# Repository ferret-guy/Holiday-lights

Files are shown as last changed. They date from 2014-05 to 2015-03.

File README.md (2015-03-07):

Holiday-Magic-Lights code

All recent developments are in ./HolidayLights/led_ir

Developed on Aquino IDE 1.05 and Arduino IDE 1.5.6r2

Todo:
    Add Basic Animations
        Scrolling
        Twinkling
        Rainbow
    Add more colors
	Add IR capability
	Fix even-number separation modes

NOTES:
Writing to strip of 144 length is 1.25ms
Writing to strip of 045 length is 1.35ms (what?)
Writing to strip of 189 length is 1.58ms
Writing to strip of 300 length is 1.85ms (specified maximum)

MODES:
0 - Off
1 - Separation Mode (Including Chaser Mode)
2 - Solid Mode
3 - Rainbow Mode
4 - Blink Mode
5 - Twinkle Mode

SPECIAL CONTROLS:
Special features activated through mode button (5th row, 2nd column):

1.
In Separation Mode, Switches through seperation modes (Starts at 1, goes to 2, then 3, then 0, then 1 again)
Mode number is now many times each color occurs.
!! Separation mode 0 is chaser mode. !!

2.
In Solid Mode, cycles through preset strip lengths. IN DEVELOPMENT FIRMWARE, THIS IS:
	45 long, 144 long, 189 long, then 45 long again.
THIS WILL BE CHANGED TO INTERVALS OF 60 FOR PRODUCTION?

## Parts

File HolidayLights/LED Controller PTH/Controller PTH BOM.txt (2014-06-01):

   ╔═════════════════════════════════════════════════╗
   ║LED Controller PTH Prototype -- Bill of Materials║
╔══╩════════════╦═══════╦═══════════════════╦════════╩══╗
║ Component     ║ Name  ║ Digikey P/N       ║ Price     ║
╠═══════════════╬═══════╬═══════════════════╬═══════════╣
║ 0.1uF         ║ C1    ║ 399-9845-ND       ║ $0.45     ║
║ 0.1uF         ║ C2    ║ 399-9845-ND       ║ $0.45     ║
║ 0.1uF         ║ C5    ║ 399-9845-ND       ║ $0.45     ║
║ 0.1uF         ║ C6    ║ 399-9845-ND       ║ $0.45     ║
║ 0.33uF        ║ C3    ║ 493-12794-1-ND    ║ $0.17     ║
║ 1uF           ║ C4    ║ UKL1H010KDDANA-ND ║ $0.42     ║
║ ATMEGA328-P   ║ IC1   ║ ATMEGA328-PU-ND   ║ $3.41     ║
║ CONN_3        ║ K1    ║ 5-826951-0-ND     ║ $0.20*    ║
║ CONN_6        ║ P1    ║ 5-826951-0-ND     ║ $0.40*    ║
║ TSOP38238     ║ Q1    ║ 751-1227-ND       ║ $1.12     ║
║ ZTT-16.00MX   ║ Q2    ║ X908-ND           ║ $0.70     ║
║ 300           ║ R2    ║ CF14JT300RCT-ND   ║ $0.08     ║
║ 10K           ║ R1    ║ CF14JT10K0CT-ND   ║ $0.08     ║
║ LM7905CT      ║ U1    ║ NCP7805TGOS-ND    ║ $0.46     ║
╠═══════════════╬═══════╬═══════════════════╬═══════════╣
║ TOTAL COST    ║░░░░░░░║░░░░░░░░░░░░░░░░░░░║ $11.54    ║
╠═══════════════╩═══════╩═══════════════════╩═══════════╣
║*Calculated from total cost of 50-position breakaway.  ║
║ Total cost is increased due to this.                  ║
╚═══════════════════════════════════════════════════════╝

201 205 203 205 187 ╔═╦═╗
186 176 186 177 186 ║░║▒║
204 205 206 205 185 ╠═╬═╣
186 178 186 219 186 ║▓║█║
200 205 202 205 188 ╚═╩═╝

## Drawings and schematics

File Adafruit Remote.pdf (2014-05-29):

# Adafruit IR Codes

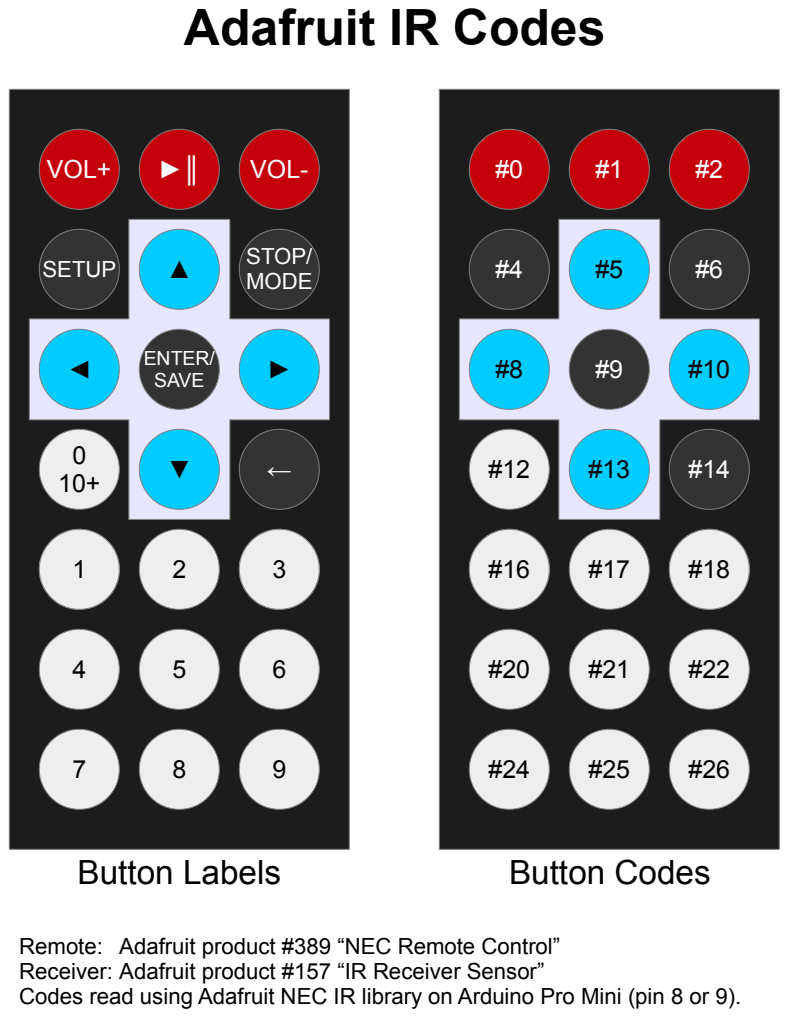
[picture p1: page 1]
VOL+; VOL-; SETUP; STOP/; MODE; ENTER/ SAVE; Button Labels; Button Codes

Remote: Adafruit product #389 “NEC Remote Control”
Receiver: Adafruit product #157 “IR Receiver Sensor”
Codes read using Adafruit NEC IR library on Arduino Pro Mini (pin 8 or 9).

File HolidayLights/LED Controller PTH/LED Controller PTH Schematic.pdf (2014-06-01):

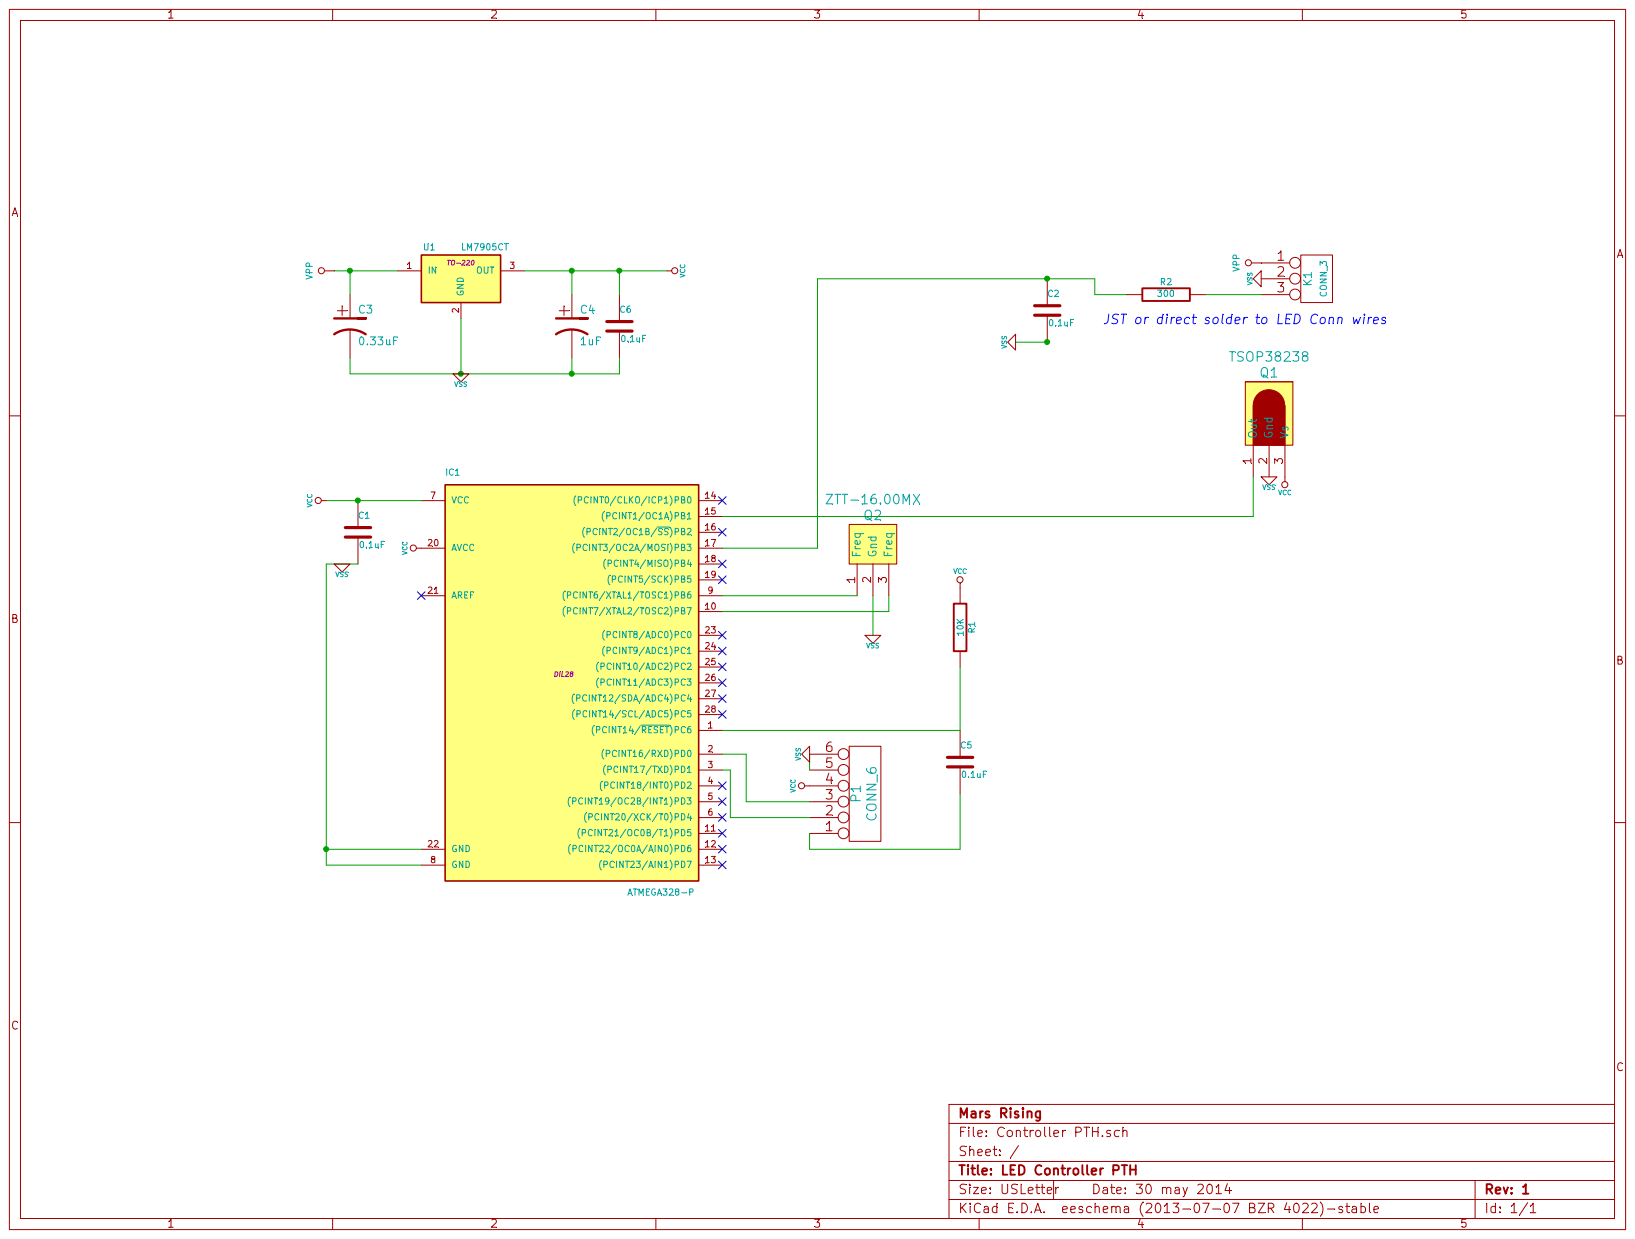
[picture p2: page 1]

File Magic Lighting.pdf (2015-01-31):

# “Magic Lighting” Remote IR Codes

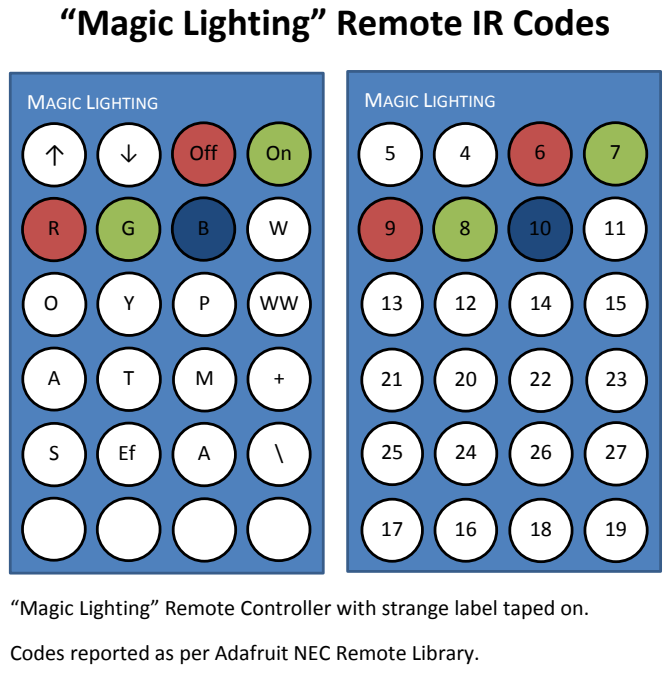
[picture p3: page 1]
MAGIC LIGHTING; Off

“Magic Lighting” Remote Controller with strange label taped on.

Codes reported as per Adafruit NEC Remote Library.

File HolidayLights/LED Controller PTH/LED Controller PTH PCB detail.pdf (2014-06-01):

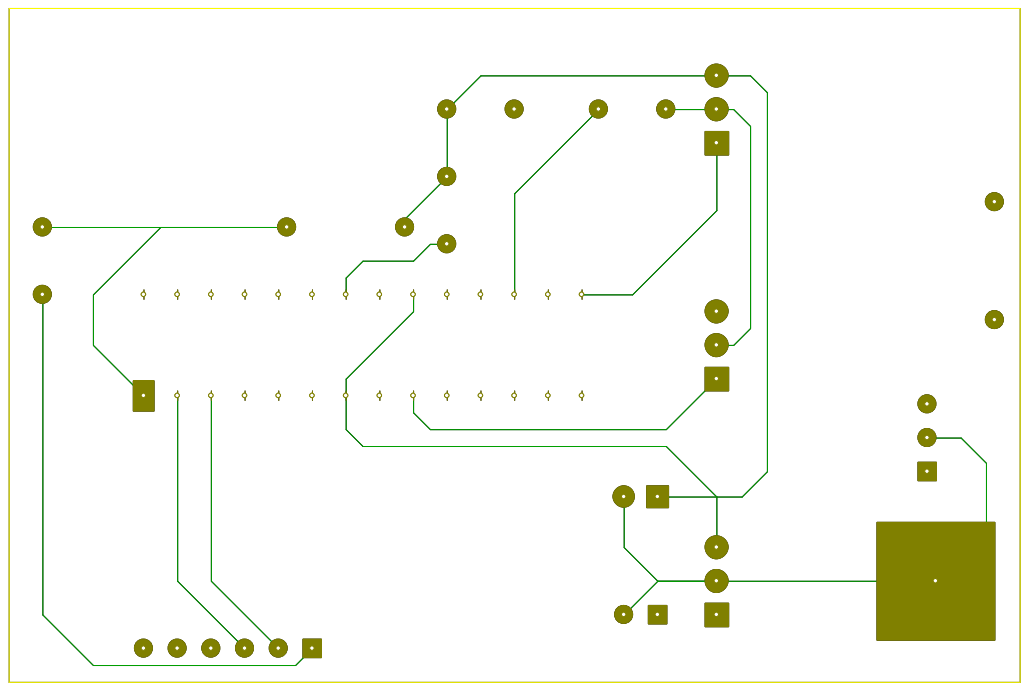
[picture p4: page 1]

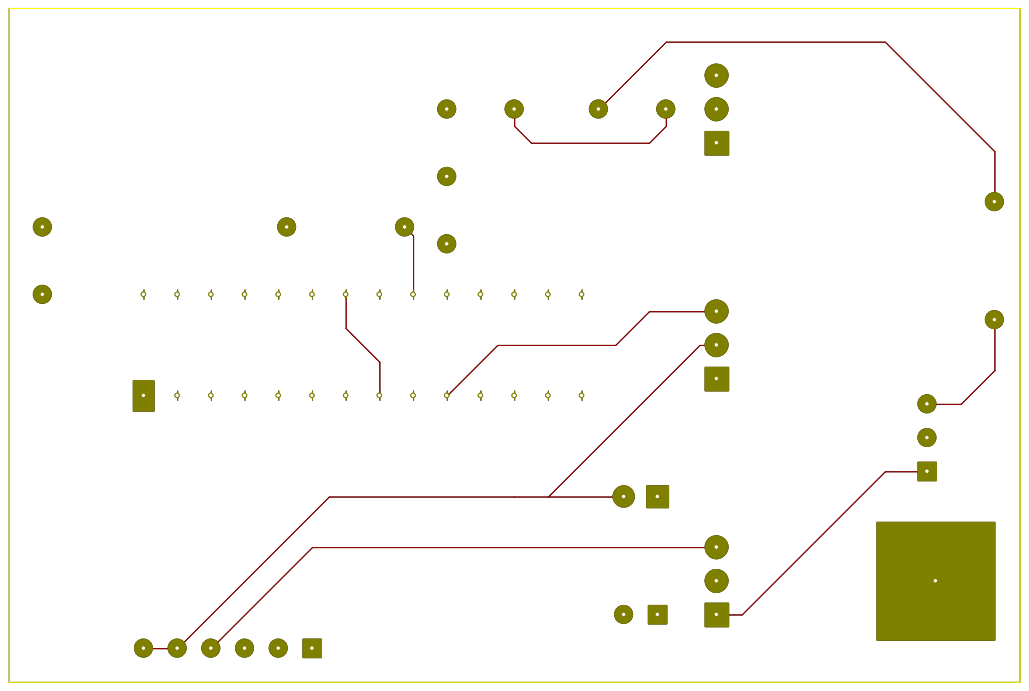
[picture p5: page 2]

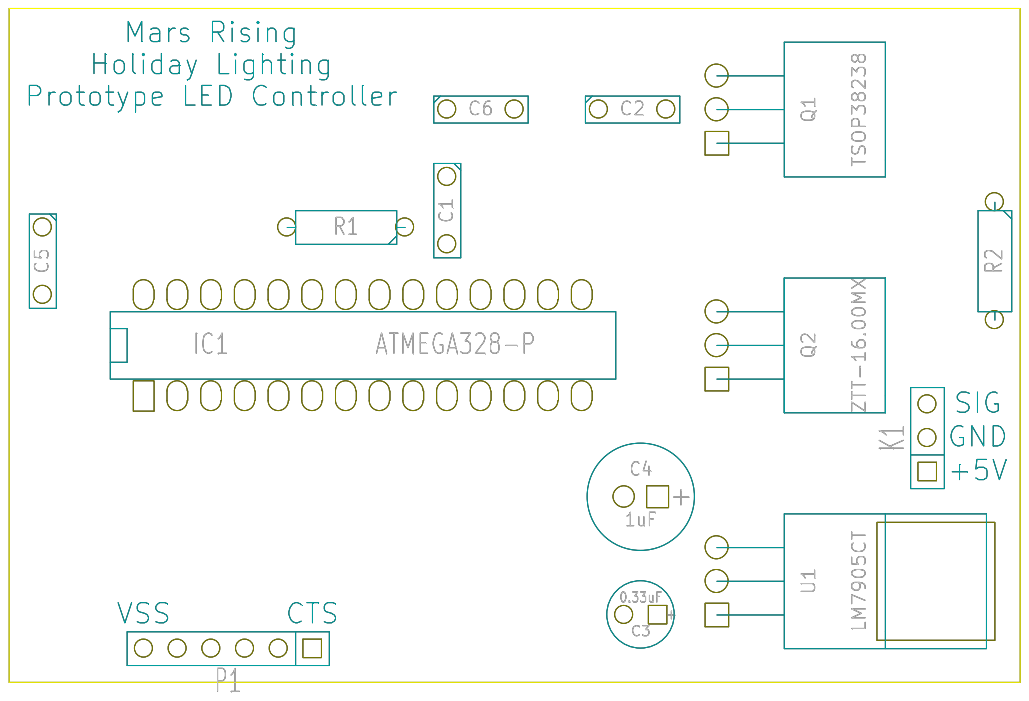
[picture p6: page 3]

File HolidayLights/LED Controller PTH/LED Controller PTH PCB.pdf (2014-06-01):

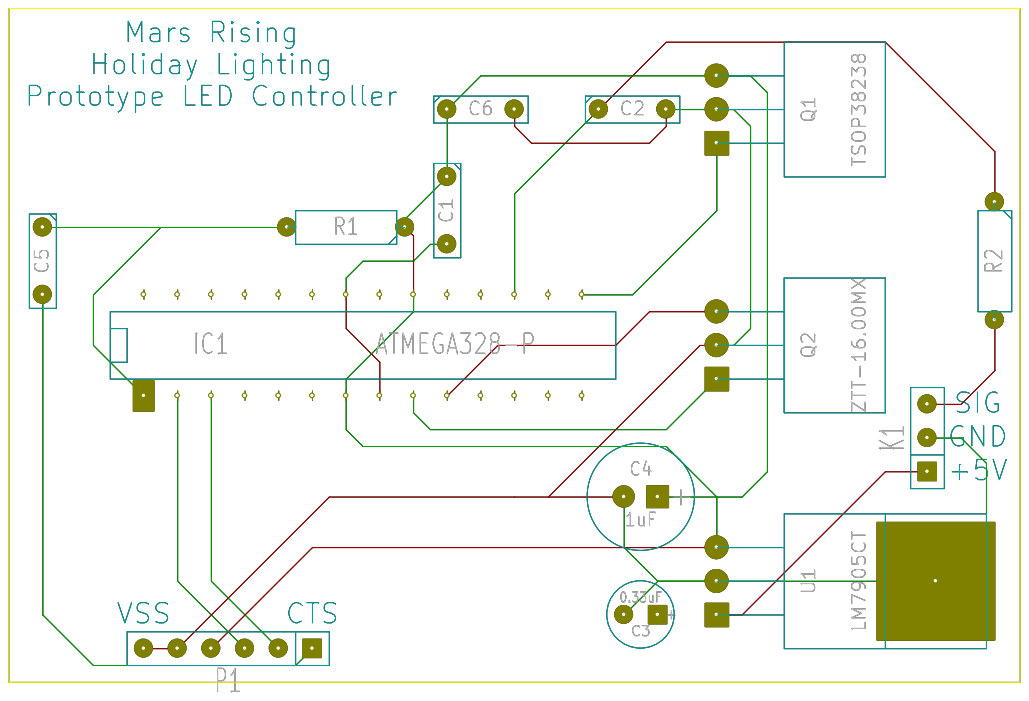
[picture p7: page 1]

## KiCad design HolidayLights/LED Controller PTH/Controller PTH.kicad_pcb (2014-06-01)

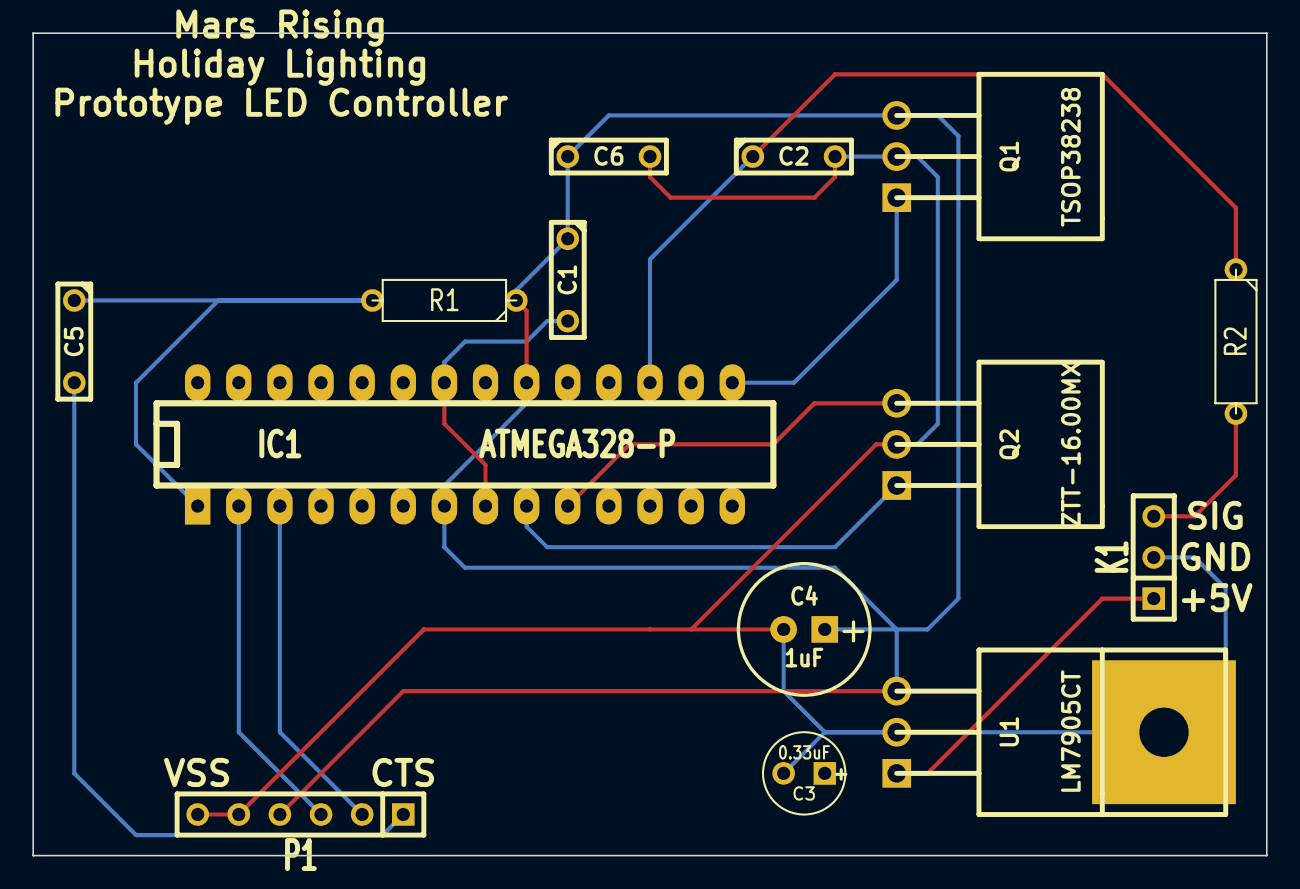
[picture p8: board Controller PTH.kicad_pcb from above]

Board: 2 copper layers, 76.2 x 50.8 mm, 14 parts (0 on the bottom side), 13 nets.

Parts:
C1, C2, C5, C6: 0.1uF; C2
C3: 0.33uF; C1V5
C4: 1uF; C1V8
IC1: ATMEGA328-P; DIP-28__300_ELL
K1: CONN_3; SIL-3
P1: CONN_6; SIL-6
Q1: TSOP38238; TO220
Q2: ZTT-16.00MX; TO220
R1: 10K; R3-5
R2: 300; R3-5
U1: LM7905CT; TO220

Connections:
unnamed: C5.1, IC1.1, R1.2
unnamed: IC1.3, P1.2
unnamed: C5.2, P1.1
unnamed: K1.3, R2.2
unnamed: IC1.15, Q1.1
unnamed: C2.1, IC1.17, R2.1
unnamed: C1.2, IC1.8, IC1.22
unnamed: IC1.9, Q2.1
unnamed: IC1.10, Q2.3
unnamed: IC1.2, P1.3
VCC: C1.1, C4.1, C6.1, IC1.7, IC1.20, P1.4, Q1.3, R1.1, U1.3
VPP: C3.1, K1.1, U1.1
VSS: C2.2, C3.2, C4.2, C6.2, K1.2, P1.5, P1.6, Q1.2, Q2.2, U1.2

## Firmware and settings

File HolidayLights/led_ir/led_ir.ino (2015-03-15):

#include "AdafruitNECIR.h"
#include <Adafruit_NeoPixel.h>



// ****************************************** Defines and Globals Go Here

//Pin the strip is on.
#define PIN 7
//Pin the IR Sensor is on.
#define IRpin 3

//Serial Definitions
#define STARTBIT          253
#define STOPBIT           254
#define FILLSTRIPSIG      44
#define UPDATECOLORSIG    50
#define PREVIEWPIXELSIG   60
#define SETPIXELSIG       61
#define CLEARPIXELSIG     62
#define CHANGECOLSIG      30
#define SEPMODESIG        40
#define KILLSEPBIT        31

#define NUMMODES          6        //Number of modes, including off.
#define NUMLENGTHS        3        //Number of preset lengths.
#define MAXLEDS           300      //Specified maximum number of LEDS.

#define MINCOLORS         1        //The minimum number of colors allowed in separation mode. i.e. the user can turn off colors until they have this many.
#define MAXSPEED          20       //Maximum animation speed in milliseconds.
#define MINSPEED          250      //Minimum animation speed in milliseconds. Below this speed stops moving.
#define SPEEDSTEP         15       //The time by which speed in adjusted in milliseconds.

//Define our globals.
int       led_num         = 144;    //Total number of LEDs, zero-ordinated.
int       cur_len         = 1;     //The current length preset.
int       col_tot         = 11;    //Total colors defined. This will almost certainly be 11, but there's nothing wrong with a little open-endedness.
int       col_len         = 0;     //The length of each color segment. This is calculated later.
float     col_fln         = 0;     //The floating-point color length.
int       col_seg         = 0;     //The length of each separation mode segment.
int       col_num         = 0;     //The number of active/enabled colors. This is calculated later.
int       col_rep         = 0;     //The number of times to draw the colors in color separation mode 2+.
int       ren_stp         = 0;     //The number of iterations the rendering loop goes through before resetting. This is calculated later.
int       ren_stp_b       = 256;   //Rainbow steps.
int       ren_glx         = 0;     //Useful for resuming color separation mode as opposed to restarting the animation.
int       ren_glx_b       = 0;     //Useful for rainbows.
int       ren_bri         = 255;   //Global brightness multiplier. 255 is fullbright, 0 is blackout.
int       sep_mod         = 1;     //The current separation mode.
int       sep_prv         = 1;     //The previous separation mode.
int       sep_dly         = 265;   //The current animation frame delay.
int       absolute_offset = 0;     //The number of pixels to skip when drawing. Artifact from an old devkit.
int       cmd_last        = 0;     //The last IR code recieved.
int       cmd_prev        = 0;     //The one before that.
int       mode_state      = 0;     //The current mode.
int       mode_last       = 1;     //The mode before we turned off. Also lets us turn on to solid mode, apparently.
int       ani_dir         = 0;     //Direction of animation progression, 0 is forward, 1 is reverse.
int       ani_go          = 0;     //Should the animation be going?
int       efc_col         = 3;     //Current color for Twinkle and Blink

//Initialize our strip. There needs to be a way to clear this out, because when additional physical LED strips are added, the length can only be changed by redefining the strip.
Adafruit_NeoPixel strip = Adafruit_NeoPixel(MAXLEDS+absolute_offset+1, PIN, NEO_GRB + NEO_KHZ800);
//Initialize our IR sensor.
Adafruit_NECremote remote(IRpin);

//Colors:
//0.  Red
//1.  Green
//2.  Blue
//3.  White
//4.  Orange
//5.  Yellow
//6.  Purple
//7.  Warm White
//8.  Turquoise
//9.  Magenta
//10. Amber

//Mask of enabled colors.
boolean color_enable[] = {0,0,0,1,0,0,0,0,0,0,0};
//The color definitions themselves.
uint32_t colors[] = {
  strip.Color(255,0,0),      //Red
  strip.Color(0,255,0),      //Green
  strip.Color(0,0,255),      //Blue
  strip.Color(255,255,255),  //White
  strip.Color(255,100,0),    //Orange
  strip.Color(255,255,0),    //Yellow
  strip.Color(128,0,128),    //Purple
  strip.Color(255,178,48),   //Warm White
  strip.Color(175,238,238),  //Turquoise
  strip.Color(255,0,128),    //Magenta
  strip.Color(255,200,25)    //Amber
};

//Alternatively, for twinkle...
int colorparts[11][3] = {
  {255,0,0},
  {0,255,0},
  {0,0,255},
  {255,255,255},
  {255,100,0},
  {255,255,0},
  {128,0,128},
  {255,178,48},
  {175,238,238},
  {255,0,128},
  {255,200,25}
};

//Predefined, switchable strip lengths.
int lengths[] = {
  45,
  144,
  189
};

//MODE TABLE - Important stuff.
void (*modes[])() = {
  *ModeOffHndlr,
  *ModeSepModHndlr,
  *ModeSolidHndlr,
  *ModeRainbowHndlr,
  *ModeBlinkHndlr,
  *ModeTwinkleHndlr
};
  

// ****************************************** General Purpose Functions Go Here

//Literally Nothing
void dust(){}

//Nothing For Your Something
void dust2(int cs_s){}

//Calculate the length of each color segment based on the length of the strip and the separation mode. (This is col_len.)
int CalcCL(int spm){
  //Preset the color length to one, in case separation mode is zero.
  int ccl = 1;
  //If separation mode is non-zero...
  if(spm>0){
    //The color length is calculated.
    if(col_num>0){
      ccl = ceil(((led_num/spm)/col_num));
      if(ccl<1){ccl=1;}
      //Calculate the floating-point color length.
      col_fln = (led_num/spm)/col_num;
      col_seg = (int) (ccl*col_num);
      col_rep = led_num/col_seg;
    }else{ccl=1;}
  }
  return ccl;
}

//Calculate the number of colors enabled. (This is col_num.)
int CalcCN(boolean cle[]){
  int cur=0;
  //Iterate through the color_enable mask and add one to the proto-col_num everytime we find a high bit.
  for(int cc=0;cc<col_tot;cc++){
    if(cle[cc]){cur++;}
  }
  if(cur==0){cur=1;}
  return cur;
}

//Initialize our strips(s). This is where strip redefinition would need to happen.
void initStrips(boolean cle[],int spm){
  //Update our globals.
  col_num = CalcCN(cle);
  col_len = CalcCL(spm);
  //Set the number of render steps.
  if(spm>0){
    ren_stp = col_seg;
  }else{
    ren_stp = led_num;
  }
  //Initialize our strip.
  strip.begin();
  strip.setBrightness(ren_bri);
  strip.show();
}

//Fill the strip with a color.
void FillStrip(int cr, int cg, int cb){
  //Construct the selected color.
  uint32_t nc=strip.Color(cr,cg,cb);
  //Step through each pixel and set it to the selected color.
    for(int i=0;i<=led_num;i++){
      strip.setPixelColor(i+absolute_offset,nc);
  }
}

//Fill the strip with a predefined color.
void FillStripC(uint32_t nc){
  //Step through each pixel and set it to the selected color.
    for(int i=0;i<=led_num;i++){
      strip.setPixelColor(i+absolute_offset,nc);
  }
}

//Adafruit colorwheel function... no need to reinvent the wheel.
uint32_t Wheel(byte WheelPos) {
  WheelPos = 255 - WheelPos;
  if(WheelPos < 85) {
   return strip.Color(255 - WheelPos * 3, 0, WheelPos * 3);
  } else if(WheelPos < 170) {
    WheelPos -= 85;
   return strip.Color(0, WheelPos * 3, 255 - WheelPos * 3);
  } else {
   WheelPos -= 170;
   return strip.Color(WheelPos * 3, 255 - WheelPos * 3, 0);
  }
}

//Increment or decrement a variable to progress animation.
int progressAnimation(int input){
  int output;
  //Serial.println("got called");
  //Serial.println(input);
  if(ani_go==1){
    if(ani_dir==1){
      //Serial.println("minus minus");
      output = input-1;
    }else{
      //Serial.println("plus plus");
      output = input+1;
    }
  }else{
    output=input;
  }
  //Serial.println(output);
  return output;
}



// ****************************************** Renderers Go Here

//The separation mode renderer!
void RenderSPM(int offset){
  //Initialize the incrementing variables.
  int rend_step = 1; //NOT TO BE CONFUSED WITH ren_stp.
  int col_step = 0;
  int spm_step = -1;
  //Make sure we have a workable number of colors
  if(col_num>1){
    //If separation mode is 1 or higher...
    if(sep_mod>0){
      //This while loop increments spm_step to draw multiple instances of the separation for modes 2 and up.
      while(spm_step<=col_rep){
        col_step=0;
        rend_step=0;
        //This while loop steps through the different colors.
        while(col_step<col_tot){
          //If the color is enabled, render it.
          if(color_enable[col_step]){
            //Calculate what pixel we should be drawing to.                 \/ This is where we move over a lot for separation mode 2+.
            int pixnum=(rend_step*(col_len))+offset+(col_seg*spm_step);
            //Don't draw to pixels lower than the absolute offset.
            if(pixnum<0){
              pixnum=-absolute_offset-1;
            }
            //Draw the pixel in the correct color.
            strip.setPixelColor(pixnum+absolute_offset,colors[col_step]);
            //Go to the next color length.
            rend_step++;
          }
          //Go to the next color.
          col_step++;
        }
        //Draw the next separation instance.
        spm_step++;
      }
    //Draw separation mode 0. We handle this separately as the effect achived is actually the expected result of the separation mode approaching infinity, where as true mode zero would be a single color of infinite length.
    }else{
      //Pretty simple stuff. It won't need changing, ever.
      //Calculate how many times the pattern needs repeating.
      int led_rpt=led_num/col_num;
      //Initialize a thing.
      int pixnum=0;
      int stepnum=0;
      //Step through the colors.
      while(col_step<col_tot){
        //If a color is enabled, draw it.
        if(color_enable[col_step]){
          //Repeat it however many times with the offset increased by the total colors.
          for(int i=0;i<led_num;i+=col_num){
            pixnum = stepnum+i+offset;
            if(pixnum>=led_num){pixnum-=led_num;}
            //Actually draw the pixel.
            strip.setPixelColor(pixnum+absolute_offset,colors[col_step]);
          }
          stepnum++;
        }
        //Go to the next color.
        col_step++;
      }
    }
  //If there is only one color enabled, it is a solid mode.
  }else if(col_num==1){
    //Look until we find the enabled color.
    while(col_step<col_tot){
      if(color_enable[col_step]){
        FillStripC(colors[col_step]);
      }
      //Go to the next color.
      col_step++;
    }
  //If there are no colors enabled, draw black, so as to not break everything.
  }else{
    FillStrip(0,0,0);
  }
  //Actually send all these changes to the strip. We do this SOMEWHERE ELSE for due to major opimization issues, as well as to avoid visually staggered rendering.
  //strip.show();
}

//Predraw all the pixels so separation mode doesn't fill over initial black.
void SPMPreRender(int offs){
  for(int x=offs;x<col_len+offs;x++){
    RenderSPM(x);
  }
  strip.show();
}

//Do a rainbow.
void RenderRainbow(uint16_t j) {
  uint16_t i;
    for(i=0; i<strip.numPixels(); i++) {
      strip.setPixelColor(i, Wheel((i+j) & 255));
    }
    strip.show();
}

//Twinkly.
void RenderTwinkle(int index){
  int n;
  for(n=0;n<(led_num/4);n++){
    float r = (float) colorparts[index][0];
    //float r = 255;
    float g = (float) colorparts[index][1];
    //float g = 0;
    float b = (float) colorparts[index][2];
    //float b = 0;
    float di = (float) random(100);
    float d = (di/125)+0.2;
    r = r*d;
    g = g*d;
    b = b*d;
    int ri = (int) r;
    int gi = (int) g;
    int bi = (int) b;
    uint32_t color = strip.Color(ri,gi,bi);
    strip.setPixelColor(random(led_num),color);
  }
  strip.show();
}
    


// ****************************************** Button Handlers Go Here

//Handle mode button in sepmod
void SepModModeHndlr(){
  if (sep_mod == 3){sep_mod = 0;}
  else {sep_mod++;}
  ren_glx = 0;
}

void colenable(int index){
  if(col_num>MINCOLORS){
    if (color_enable[index]==1){
      color_enable[index]=0;
    }else{
      color_enable[index]=1;
    }
    ren_glx = 0;
  }else{color_enable[index]=1;}
}

void BlinkTwinkleColorHndlr(int index){
  efc_col=index;
}

void SolidColorHndlr(int index){
  FillStripC(colors[index]);
}

void SolidModeHndlr(){
  cur_len++;
  if(cur_len==NUMLENGTHS){cur_len=0;}
  led_num=lengths[cur_len];
  initStrips(color_enable,sep_mod);
}



// ****************************************** Top-Level Handlers Go Here

//Single byte command processor. This is split out so that we can take commands during ANY MODE with ease. Handlers for mode-specific events are passed in.
int SingleByteCommand(int csig, void (*colHndlr)(int), void (*modHndlr)(), bool volatileColors){
  int gret=0;
  
  //colHndlr is called when any color button is pressed, parameter passed is color number as per array up top.
  //modHndlr is called when mode button is pressed, no paramter is passed.
  
  switch(csig){
    //DO COLORS
    //Red
    case 9:
      colHndlr(0);
      if(!volatileColors){gret=1;}
      break;
      
    //Green
    case 8:
      colHndlr(1);
      if(!volatileColors){gret=1;}
      break;
    
    //Blue
    case 10:
      colHndlr(2);
      if(!volatileColors){gret=1;}
      break;
  
    //White
    case 11: 
      colHndlr(3);
      if(!volatileColors){gret=1;}
      break;
    
    //Orange
    case 13:
      colHndlr(4);
      if(!volatileColors){gret=1;}
      break;
    
    //Yellow
    case 12:
      colHndlr(5);
      if(!volatileColors){gret=1;}
      break;
    
    //Purple
    case 14:
      colHndlr(6);
      if(!volatileColors){gret=1;}
      break;
    
    //Warm White
    case 15:
      colHndlr(7);
      if(!volatileColors){gret=1;}
      break;
    
    //Turquoise
    case 20:
      colHndlr(8);
      if(!volatileColors){gret=1;}
      break;
    
    //Magenta
    case 22:
      colHndlr(9);
      if(!volatileColors){gret=1;}
      break;
    
    //Amber
    case 21:
      colHndlr(10);
      if(!volatileColors){gret=1;}
      break;
    
    //DO ADJUSTMENTS
    //Speed Down
    case 27:
      sep_dly+=SPEEDSTEP;
      if(sep_dly>MINSPEED){
        sep_dly=MINSPEED+SPEEDSTEP;
      }
      if(sep_dly>MINSPEED){ani_go=0;}
      gret=1;
      break;
    
    //Speed Up
    case 23:
      sep_dly-=SPEEDSTEP;
      if(sep_dly<MAXSPEED){
        sep_dly=MAXSPEED;
      }
      if(sep_dly<=MINSPEED){ani_go=1;}
      gret=1;
      break;
    
    //Brightness Down
    case 4:
      ren_bri-=15;
      if(ren_bri<15){
        ren_bri=15;
      }
      gret=1;
      strip.setBrightness(ren_bri);
      break;
    
    //Brightness Up
    case 5:
      ren_bri+=15;
      if(ren_bri>255){
        ren_bri=255;
      }
      gret=1;
      strip.setBrightness(ren_bri);
      break;
    
    //DO THESE MISCELLANEOUS STUFF
    //Mode Button Handler
    case 24:
      modHndlr();
      break;
    
    //Someone held down the button, and we haven't implemented that yet.
    case -3:
      gret=1;
      break;
    
    //Reverse the animation progression.
    case 19:
      if(ani_dir==1){
        ani_dir=0; //forward
      }else{
        ani_dir=1; //reverse
      }
      gret=1;
      break;
    
    //DO MODES
    //Turn On
    case 7:
      if(mode_state!=0){gret=1;}
      if(mode_last==0){mode_last=1;}
      mode_state=mode_last;
      break;
    
    //Off Mode
    case 6:
      if(mode_state!=0){
        mode_last=mode_state;
      }
      mode_state=0;
      break;
    
    //Separation Mode
    case 26:
      mode_state=1;
      break;
    
    //Solid Mode
    case 25:
      mode_state=2;
      break;
    
    //Rainbow Mode
    case 17:
      mode_state=3;
      break;
    
    //Blink Mode
    case 16:
      mode_state=4;
      break;
    
    //Twinkle Mode
    case 18:
      mode_state=5;
      break;
      
    default:
      gret=1;
      break;
    
  }  
  return gret;
}

//Accept commands and be blank.
void ModeOffHndlr(){
  FillStrip(0,0,0);
  strip.show();
  while(1==1){
    cmd_last=remote.listen(250);
    int cret=SingleByteCommand(cmd_last,*dust2,*dust,false);
    if(cret==0){break;}
  }
}

//Run separation mode.
void ModeSepModHndlr(){
  //Re-intialize the strip with the selected parameters.
  initStrips(color_enable,sep_mod);
  //Initialize our breaking var.
  int i=1;
  //If we're not resuming separation mode, predraw the colors so we don't have empty pixels visible.
  if(ren_glx==0){
    //Render a single color-length.
    SPMPreRender(0);
    //Update our resume variable for when we actually start rendering.
    ren_glx=col_len;
  }else{
    SPMPreRender(ren_glx-col_len);
  }
  //Keep going until told to stop.
  while(i==1){
    //Run through the calculated number of rendering steps. Start where we stopped.
    //for(int x=ren_glx;x<ren_stp;progressAnimation(x)){
      //Serial.println("start");
      //Serial.println(ren_glx);
      int x = ren_glx;
      //Render it!
      RenderSPM(x);
      strip.show();
      x = progressAnimation(x);
      
      //Keep track of where we are so that we can pause and resume.
      ren_glx=x;
      //Delay the animation by the selected amount, and get an IR command. Two stones with one bird.
      cmd_last = remote.listen(sep_dly);
      //Serial.println("progresses");
      //Serial.println(ren_glx);
      int cret = 1;
      if(cmd_last>0){cret=SingleByteCommand(cmd_last,*colenable,*SepModModeHndlr,true);}//Run the IR command.
      //Serial.println(cret);
      //if(cmd_last==6||cmd_last==25){i=0;FillStrip(0,0,0);strip.show();break;}//If the command is right, break from the sepmod loop.
      if(cret==0){initStrips(color_enable,sep_mod);ren_glx=col_len;SPMPreRender(0);break;}//Reset and restart sepmod for necessary changes
      cmd_last = 0;//Make sure we don't re-run commands.
    //}
    //If we've made a full render, go back to rendering step zero.
    if(ani_dir==1){
      if(ren_glx==0){
        ren_glx=(ren_stp);
      }
    }else{
      if(ren_glx==(ren_stp)){
        ren_glx=0;
      }
    }
  }
}

//Does solid colors.
void ModeSolidHndlr(){
  initStrips(color_enable,sep_mod);
  int i=1;
  FillStrip(255,255,255);
  while(i==1){
    cmd_last=remote.listen(250);
    int cret = SingleByteCommand(cmd_last,*SolidColorHndlr,*SolidModeHndlr,false);
    strip.show();
    if(cret==0){i=0;break;}
    cmd_prev=cmd_last;
  }
  //FillStrip(0,0,0);
  //strip.show();
}

//Make it rainbow.
void ModeRainbowHndlr(){
  //Re-intialize the strip with the selected parameters.
  initStrips(color_enable,sep_mod);
  //Initialize our breaking var.
  int i=1;

  //Keep going until told to stop.
  while(i==1){
      int x = ren_glx_b;
      //Render it!
      RenderRainbow(x);
      x = progressAnimation(x);
      //Keep track of where we are so that we can pause and resume.
      ren_glx_b=x;
      //Delay the animation by the selected amount, and get an IR command. Two stones with one bird.
      cmd_last = remote.listen(sep_dly);
      int cret = 1;
      if(cmd_last>0){cret=SingleByteCommand(cmd_last,*dust2,*dust,false);}//Run the IR command.
      if(cret==0){break;}//Reset and restart sepmod for necessary changes
      cmd_last = 0;//Make sure we don't re-run commands.
    //If we've made a full render, go back to rendering step zero.
    if(ani_dir==1){
      if(ren_glx==0){
        ren_glx=(ren_stp_b-1);
      }
    }else{
      if(ren_glx==(ren_stp_b-1)){
        ren_glx=0;
      }
    }
  }
}

void ModeBlinkHndlr(){
  //Re-intialize the strip with the selected parameters.
  initStrips(color_enable,sep_mod);
  //Initialize our breaking var.
  int it=1;

  //Keep going until told to stop.
  while(it==1){
    for (int q=0; q < 2; q++) {
      for (int i=0; i < strip.numPixels(); i=i+2) {
        strip.setPixelColor(i+q, colors[efc_col]);
      }
      strip.show();
      //Delay the animation by the selected amount, and get an IR command. Two stones with one bird.
      cmd_last = remote.listen(sep_dly);
      int cret = 1;
      if(cmd_last>0){cret=SingleByteCommand(cmd_last,*BlinkTwinkleColorHndlr,*dust,false);}//Run the IR command.
      if(cret==0){it=0;break;}//Reset and restart sepmod for necessary changes
      cmd_last = 0;//Make sure we don't re-run commands.
      for (int i=0; i < strip.numPixels(); i=i+2) {
        strip.setPixelColor(i+q, 0);
      }
    }
  }
}

//Twinkle like stars.
void ModeTwinkleHndlr(){
  //Re-intialize the strip with the selected parameters.
  initStrips(color_enable,sep_mod);
  //Initialize our breaking var.
  int i=1;

  //Keep going until told to stop.
  while(1==1){
      RenderTwinkle(efc_col);
      cmd_last = remote.listen(sep_dly);
      int cret = 1;
      if(cmd_last>0){cret=SingleByteCommand(cmd_last,*BlinkTwinkleColorHndlr,*dust,false);}//Run the IR command.
      if(cret==0){break;}//Reset and restart sepmod for necessary changes
      cmd_last = 0;//Make sure we don't re-run commands.
  }
}

//This runs first, setting up the necessary things.
void setup(void) {
  //Do everything relevant to the LEDs.
  initStrips(color_enable,sep_mod);
  //Open our serial connection to the PC.
  Serial.begin(9600);
}

//The main chunk of the program.
void loop(void) {
  (*modes[mode_state])(); // Exciting, right?
}

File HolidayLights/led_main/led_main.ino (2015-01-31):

#include <Adafruit_NeoPixel.h>
//The strip is always on pin 7. ALWAYS.
#define PIN 11

//Serial Definitions
#define STARTBIT          253
#define STOPBIT           254
#define FILLSTRIPSIG      44
#define UPDATECOLORSIG    50
#define PREVIEWPIXELSIG   60
#define SETPIXELSIG       61
#define CLEARPIXELSIG     62
#define CHANGECOLSIG      30
#define SEPMODESIG        40
#define KILLSEPBIT        31
//[NN] - Not Necessary. This feature is not for production and probably isn't production-ready. It's just for use in development and probably only works with the LED Control Utility.

//Define our globals. Globals aren't traditionally the best, but it's an AVR with 2KB RAM.
int       led_num         = 59;    //Total number of LEDs, zero-ordinated. Due to a less than healthy mix of zero- and one-ordination, the best solution is to confuse the other algorithms with an odd number.
int       col_tot         = 11;    //Total colors defined. This will almost certainly be 11, but there's nothing wrong with a little open-endedness.
int       col_len         = 0;     //The length of each color segment. This is calculated later.
float     col_fln         = 0;     //The floating-point color length.
int       col_seg         = 0;     //The length of each separation mode segment.
int       col_num         = 0;     //The number of active/enabled colors. This is calculated later.
int       col_rep         = 0;     //The number of times to draw the colors in color separation mode 2+.
uint32_t  col_lst;                 //The last preset color passed by per-pixel mode. Dirty RAM-saving hack. [NN]
int       ren_stp         = 0;     //The number of iterations the rendering loop goes through before resetting. This is calculated later.
int       ren_lst         = -1;    //The last pixel passed by per-pixel mode. [NN]
boolean   ren_msk[256];            //The preset pixel map for per-pixel mode. Absorbs all your RAM. [NN]
int       ren_glx         = 0;     //Useful for resuming color separation mode as opposed to restarting the animation. Not really necessary.
int       ren_bri         = 255;   //Global brightness multiplier. 255 is fullbright, 0 is blackout.
int       sep_mod         = 1;     //The current separation mode.
int       sep_prv         = 1;     //The previous separation mode.
int       sep_dly         = 100;   //The current animation frame delay.
int       absolute_offset = 0;     //The number of pixels to skip when drawing. Only purpose is to skip the four NeoPixels indev. [NN]

//Initialize our strip. There needs to be a way to clear this out, because when additional physical LED strips are added, the length can only be changed by redefining the strip.
Adafruit_NeoPixel strip = Adafruit_NeoPixel(led_num+absolute_offset+1, PIN, NEO_GRB + NEO_KHZ800);

//Colors:
//0.  Red
//1.  Green
//2.  Blue
//3.  White
//4.  Orange
//5.  Yellow
//6.  Purple
//7.  Warm White
//8.  Turquoise
//9.  Magenta
//10. Amber

//Mask of enabled colors.
boolean color_enable[] = {1,1,1,1,1,1,1,1,1,1,1};
//Offset of each color in color separation mode, and possibly other modes.
int     color_offset[] = {0,1,1,2,2,3,3,4,4,5,5};
//The color definitions themselves.
uint32_t colors[] = {
  strip.Color(255,0,0),      //Red
  strip.Color(0,255,0),      //Green
  strip.Color(0,0,255),      //Blue
  strip.Color(255,255,255),  //White
  strip.Color(255,100,0),    //Orange
  strip.Color(255,255,0),    //Yellow
  strip.Color(128,0,128),    //Purple
  strip.Color(255,178,48),   //Warm White
  strip.Color(175,238,238),  //Turquoise
  strip.Color(255,0,128),    //Magenta
  strip.Color(255,200,25)    //Amber
};

void colenable(int index){
  if(col_num>2){
    if (color_enable[index]==1){
      color_enable[index]=0;
    }else{
      color_enable[index]=1;
    }
    ren_glx = 0;
  }else{color_enable[index]=1;}
}


//Calculate the length of each color segment based on the length of the strip and the separation mode. (This is col_len.)
int CalcCL(int spm){
  //Preset the color length to one, in case separation mode is zero.
  int ccl = 1;
  //If separation mode is non-zero...
  if(spm>0){
    //The color length is calculated.
    if(col_num>0){
      ccl = ceil(((led_num/spm)/col_num));
      if(ccl<1){ccl=1;}
      //Calculate the floating-point color length.
      col_fln = (led_num/spm)/col_num;
      col_seg = (int) (ccl*col_num);
      col_rep = led_num/col_seg;
    }else{ccl=1;}
    //Serial.print("CCL: ");
    //Serial.println(ccl,DEC);
    //Total up the moduli (remainders) of the integer division.
    /*
    int mcl = led_num % spm;
    mcl += (led_num/spm) % col_num;
    //mcl += ((led_num/spm)/col_num) % 2;
    //Calculate how many colors to process before increasing the offset.
    int mcs = col_tot/mcl;
    //If there is no modulus, set it to zero, because we do not need to set an offset.
    if(mcl==0){mcs=col_tot;}
    //Serial.print("MCS: ");
    //Serial.print(mcs,DEC);
    //Serial.print("; MCL: ");
    //Serial.println(mcl,DEC);
    //Intialize the offset-accumulator and the current offset.
    int mcp = 0;
    int mci = 0;
    for(int i=0;i<col_tot;i++){
      //If the color is enabled, give it an offset
      if(color_enable[i]){
        //If the offset-accumulator has reached the color-offset-step, set it to zero and increment the current offset.
        if(mcp>=mcs){
          mcp=0;
          mci++;
        }
        //This just makes it work better. It's an isolated case but still an existing case.
        if(col_num==11&&sep_mod==1){color_offset[i]=mci;}//Removed.
        //Set the offset.
        else{color_offset[i]=mci;}
        //Increment the offset-accumulator.
        mcp++;
      }
    }
    */
  }
  return ccl;
}

//Calculate the number of colors enabled. (This is col_num.)
int CalcCN(boolean cle[]){
  int cur=0;
  //Iterate through the color_enable mask and add one to the proto-col_num everytime we find a high bit.
  for(int cc=0;cc<col_tot;cc++){
    if(cle[cc]){cur++;}
  }
  if(cur==0){cur=1;}
  return cur;
}

//Initialize our strips(s). This is where strip redefinition would need to happen.
void initStrips(boolean cle[],int spm){
  //Update our globals.
  col_num = CalcCN(cle);
  col_len = CalcCL(spm);
  //Set the number of render steps.
  if(spm>0){
    ren_stp = col_seg;
  }else{
    ren_stp = led_num;
  }
  //Test debug please ignore
  //Serial.println("ren_stp:");
  //Serial.println(ren_stp,DEC);
  //Serial.println("col_len:");
  //Serial.println(col_len,DEC);
  //Serial.println("col_num:");
  //Serial.println(col_num,DEC);
  //Initialize the render mask, this is doubly unneccesary but my eyeballs were about to fall out of my head. [NN]
  for(int i=0;i<256;i++){ren_msk[i]=0;}
  //Initialize our strip.
  strip.begin();
  strip.setBrightness(ren_bri);
  strip.show();
}
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

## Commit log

2014-05-20 Added Basic LED handeling
    Added basic color traking and color handeling
2014-05-20 Added adafruit ir example code
    https://learn.adafruit.com/ir-sensor/reading-ir-commands
2014-05-22 Experemintal low ram LED
2014-05-29 Fixed odd port on arduino mini
    (bus D, pin 7 bit 7)
    [SimpleNeopixelDemo.ino]
2014-05-29 Bentchmark
    Bentchmark shows infanate sin
    [Bentchmark.ino, SimpleNeopixelDemo.ino]
2014-06-01 Total rewrite, PC control, and controller pcb.
    Created windows app and supporting controller firmware for testing and
    development.
    Completely rewrote controller firmware for improved rendering and PC
    control support.
    Created prototype Part-Through-Hole controller PCB.
    All new items are in ./HolidayLights
    [Controller PTH-B_Cu.gbl, Controller PTH-B_Mask.gbs, Controller PTH-B_SilkS.gbo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]
2014-06-01 LED Control Utility Quickfix
    A block of code used for debugging was left turned on, which created a
    large lag time.
2014-06-09 Remote Emulation and Serial Restructure
    Serial communication between PC and Arduino restructured to be variable
    byte length, increasing reliability and flexibility.
    Remote Emulator utility brought to full functionality, as well as
    remote-control functions in the firmware. Additionally, the firmware now
    processes relevant commands while color separation mode is running.
2014-06-09 Color Enabling Quickfix
    Minimum colors enabled limited to 2, as one or zero breaks everything
    until the controller is reset.
    [led_main.ino]
2015-01-31 IR is starting to happen... again.
    Documented the IR codes from the remotes and began converting current
    firmware to IR operation.
2015-01-31 Infrared is fully functional
    Also implemented the solid color button, switching modes, etc. and
    changed the old firmware slightly to work with the new dev board. Tester
    firmware also included.
2015-03-07 All kinds of overhaul
    Added rainbow mode, twinkle mode, blink mode, reversing, mode
    infrastructure, IR optimizations, strip length changing, event handlers,
    and probably some other stuff.
    [led_ir.ino, ws282x_benchmark.ino]
2015-03-15 Speed changes and pin changes
    Now starts off on separation mode with only white enabled and at zero
    speed. Also, chaser mode is fixed. Pins have been changed for actual
    platform.
    [led_ir.ino]
2015-03-15 Revert "Refix"
    This reverts commit a0446dbd24dc509682fc70a8322280eecec5673b.
    [led_ir.ino]
2015-03-15 Revert "Revert "Refix""
    This reverts commit 542e6cbcefcfbbfaa3922c073ab42bb967258520.
    [led_ir.ino]
